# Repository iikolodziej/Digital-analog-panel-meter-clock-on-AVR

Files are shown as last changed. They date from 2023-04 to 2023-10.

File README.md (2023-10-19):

# Digital-analog-panel-meter-clock-on-AVR
Digital-analog panel meter clock created with AVR Atmega328 and voltage panel meter
Main photo

## Introduction
One of the assignments at the technical university was to design a simple alarm clock. I always wanted to have a more elaborate clock made by myself - so I went further and created a clock that is a combination of modernity and tradition.
<br /> 

## Technologies Used

### Languages


### Tools and others
  

### Microcontroller


## PURPOSE: 
making a clock based on analog and OLED displays with an alarm clock function

## PRINCIPLE OF OPERATION: 
In normal mode, the system alternately displays the time and date, temperature and atmospheric pressure on the OLED screen. After pressing the button, it allows you to set the current time and alarm clock. The current hour and minute are constantly displayed on analog displays

## PARAMETERS AND FUNCTIONS: 
displaying the current time and date as well as ambient temperature and atmospheric pressure. Possibility to set an alarm clock. Magnetic connection of the power cord. Possibility of easy programming via USB and ISP.

## WORKING CONDITIONS: 
home use conditions, splash protection

## POWER SUPPLY:
mains with battery time backup

## PRECISION:
○ timekeeping accuracy better than 1 s per day,<br /> 
○ temperature measurement accuracy with an accuracy of ± 0.5°C in the range of -10 to 85°C,<br /> 
○ accuracy of atmospheric pressure measurement ± 0.06 hPa in the range of 300 - 1100 hPa<br /> 

## DIMENSIONS AND WEIGHT:
approx. 25x15x15cm, up to 500g

## HOUSING: 
plastic, transparent

## Main components:
○ Microcontroller: Atmega328P-PU<br /> 
○ Real-time chip: DS1307<br /> 
○ Analog display: 2x panel voltmeter 0-5V DC<br /> 
○ Alphanumeric display: OLED 0.91"<br /> 
○ Temperature sensor: DS18B20<br /> 
○ Barometer: BMP180<br /> 

# ELECTRONIC SCHEMATIC
obraz

# PCB
obraz

# 3D DESIGN
obraz

# 3D PRINT & MECHANICS
obraz

# ASSEMBLY STAGES
obraz

# FINAL ASSEMBLY
obraz

# START-UP AND SYSTEM TESTS
obraz

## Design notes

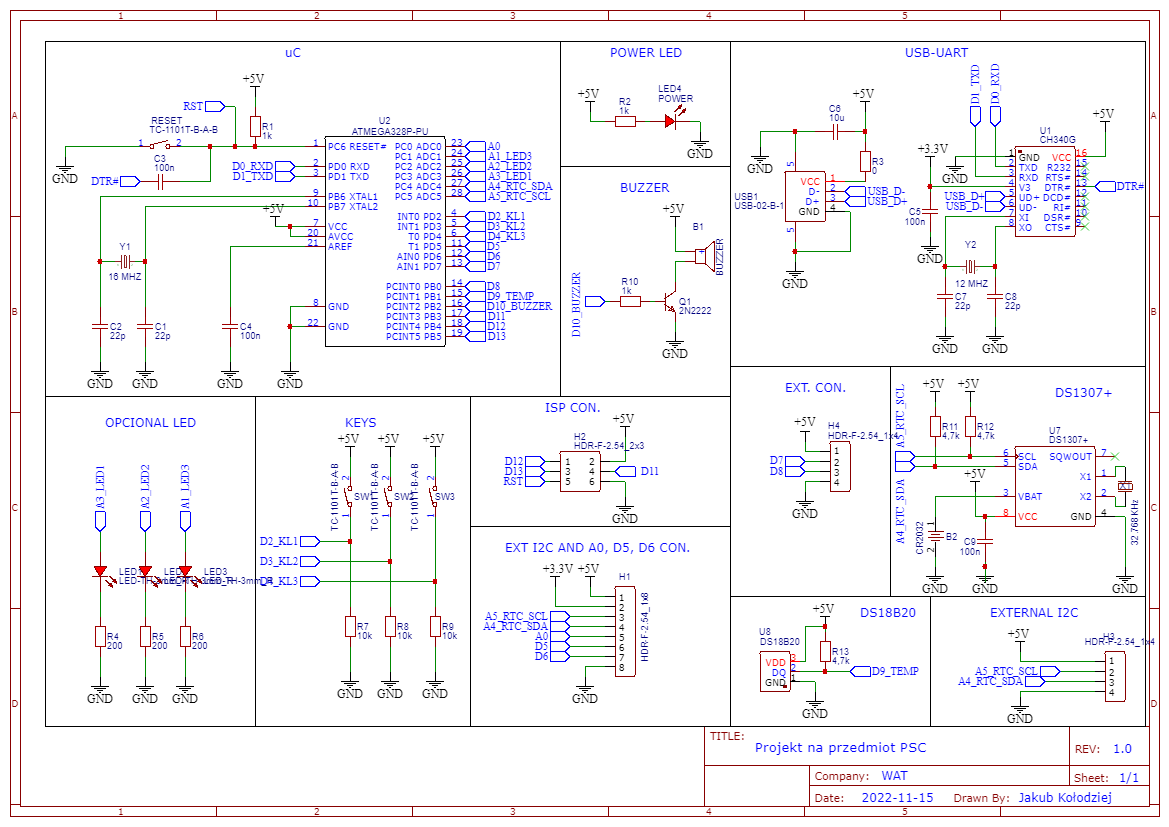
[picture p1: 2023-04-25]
images/Schematic_Budzik_JakubKolodziej_2023-01-18.png

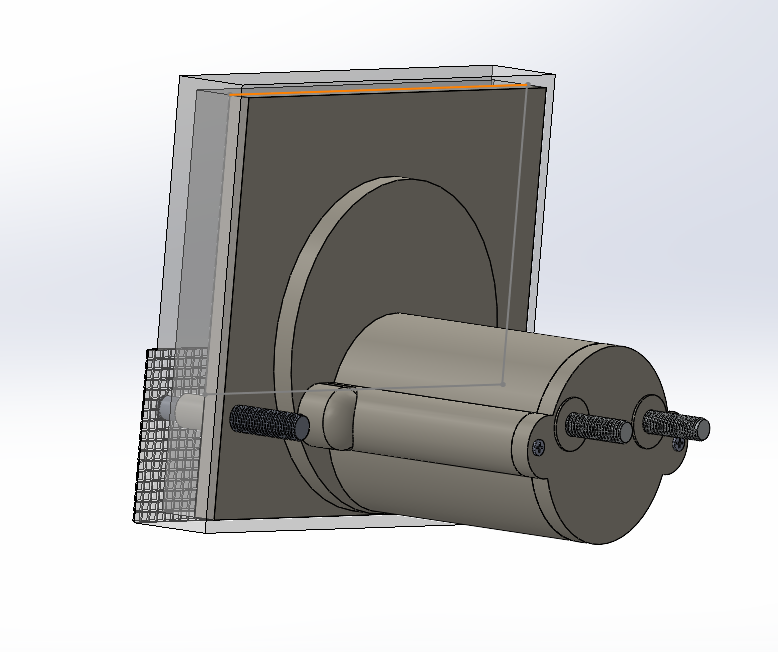
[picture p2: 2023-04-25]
images/panel meter2.png

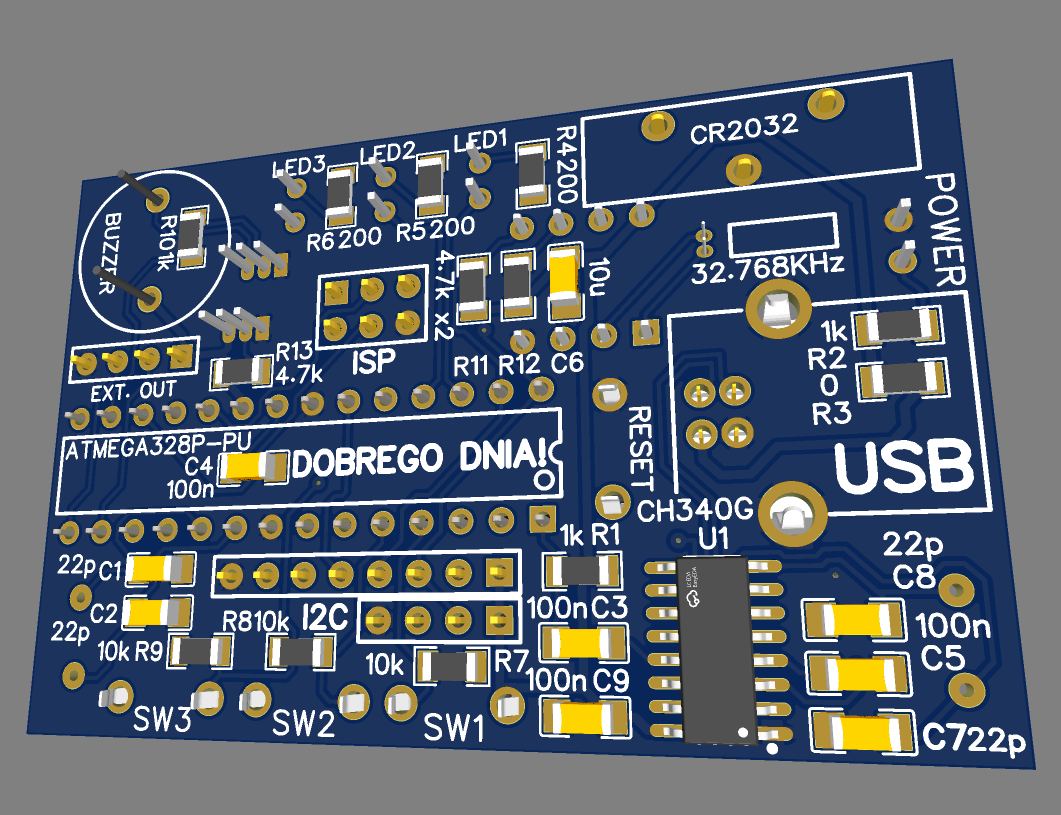
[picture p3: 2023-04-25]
images/pcb 3d bottom .png

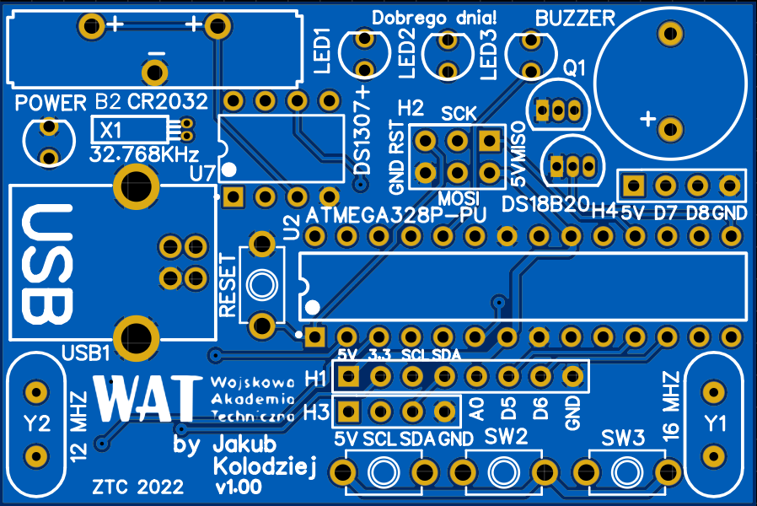
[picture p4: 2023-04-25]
images/pcb top psc.png

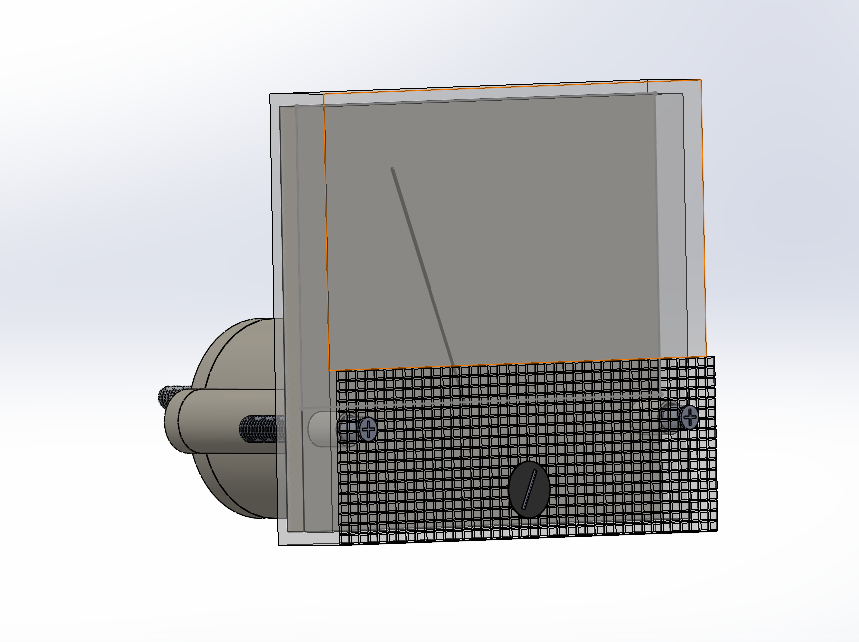
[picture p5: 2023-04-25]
images/panel meter.png

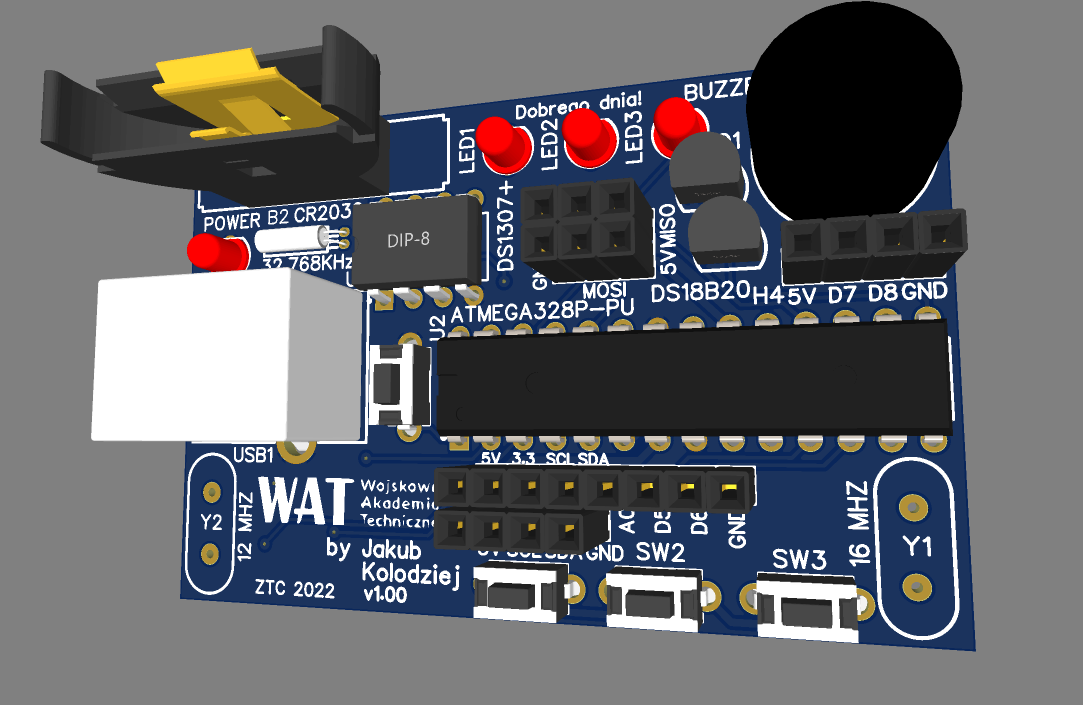
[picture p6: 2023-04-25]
images/pcb 3d top.png

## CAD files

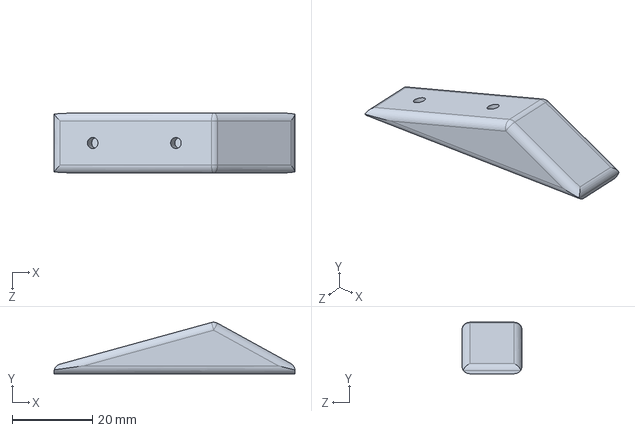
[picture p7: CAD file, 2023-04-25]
CAD elements/uchwyt podstawy do zegara analogowego.SLDPRT
60.0 x 12.9 x 15.0 mm

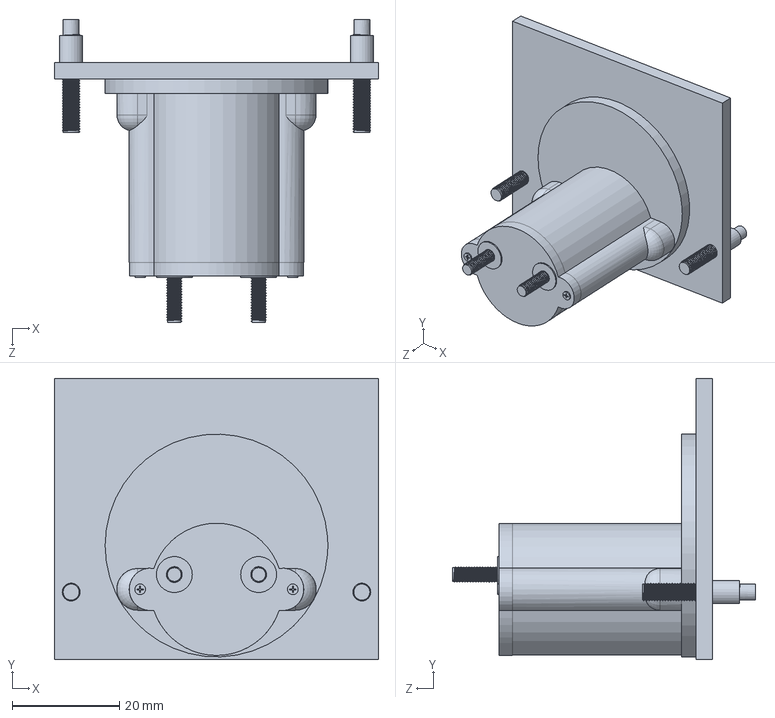
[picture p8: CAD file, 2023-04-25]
CAD elements/part001.SLDPRT
60.3 x 52.3 x 56.3 mm

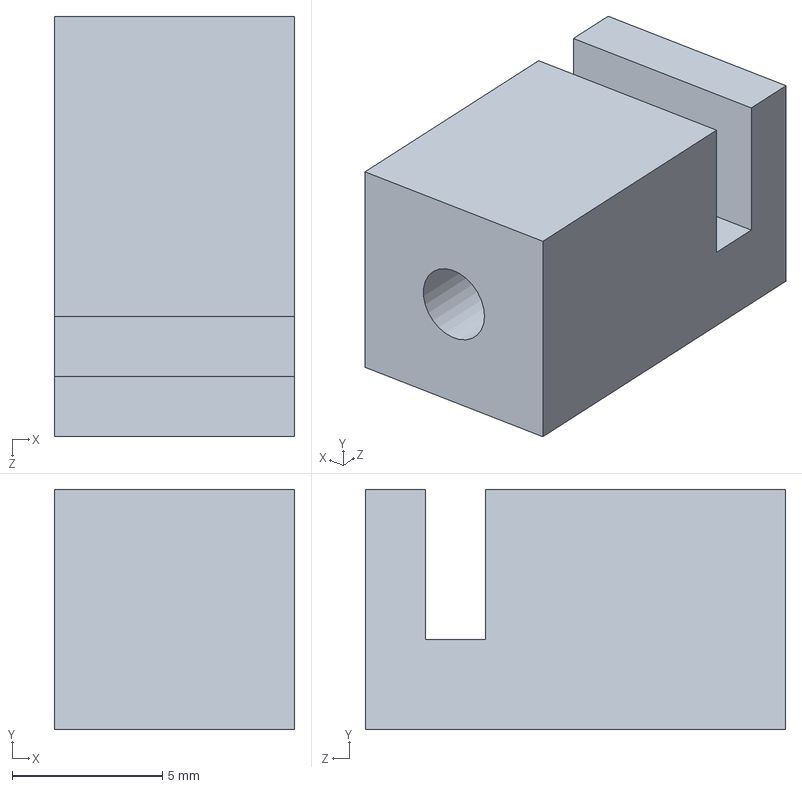
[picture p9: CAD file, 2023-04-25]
CAD elements/uchwyt 2 do zegara analogowego.SLDPRT
8.00 x 8.00 x 14.0 mm

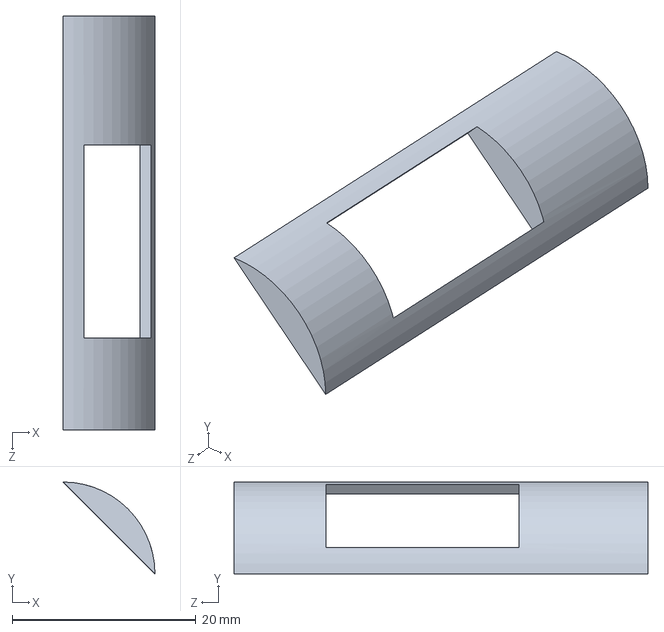
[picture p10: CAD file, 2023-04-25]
CAD elements/uchwyt 4 do zegara analogowego.SLDPRT
10.0 x 10.0 x 45.0 mm

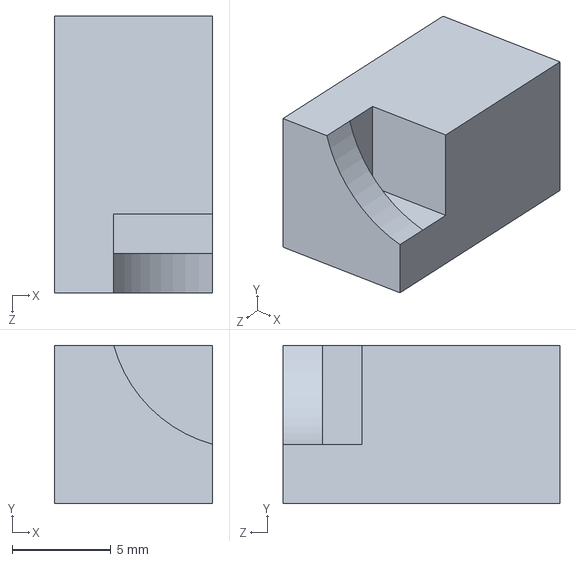
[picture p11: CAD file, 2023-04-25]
CAD elements/uchwyt 3 do zegara analogowego.SLDPRT
8.00 x 8.00 x 14.0 mm

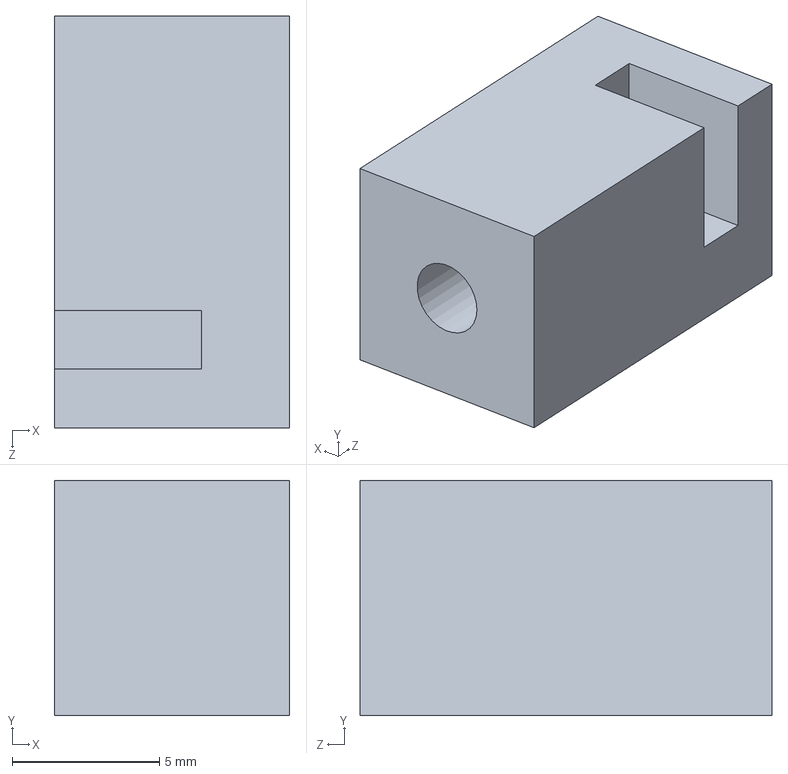
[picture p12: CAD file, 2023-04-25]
CAD elements/uchwyt 1 do zegara analogowego.SLDPRT
8.00 x 8.00 x 14.0 mm

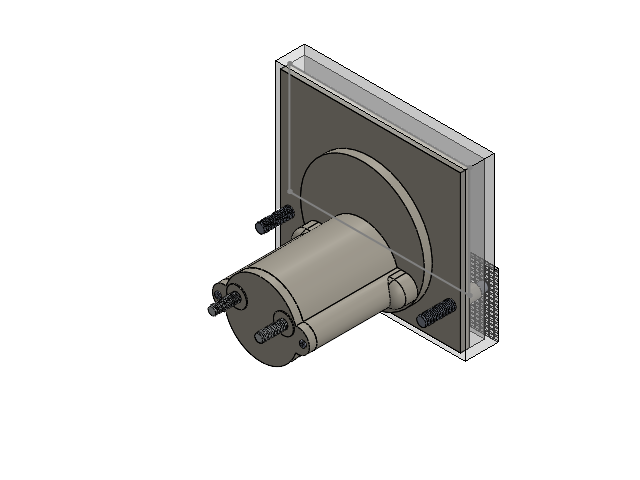
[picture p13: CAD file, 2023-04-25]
CAD elements/Assem3.SLDASM
Part3^Assem3
Part4^Assem3

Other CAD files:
CAD elements/uchwyt 1 do zegara analogowego.STL
CAD elements/uchwyt 2 do zegara analogowego.STL
CAD elements/uchwyt 3 do zegara analogowego.STL
CAD elements/uchwyt 4 do zegara analogowego.STL
CAD elements/uchwyt podstawy do zegara analogowego.STL

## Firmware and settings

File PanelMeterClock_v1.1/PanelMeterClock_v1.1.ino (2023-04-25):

/*



   Clock Display for PSC Lab in Military University of Technology


  @by Jakub Kołodziej



 */
 
#include <Wire.h>
#include <RTClib.h>
#include <Adafruit_SSD1306.h>
#include <OneWire.h>
#include <DallasTemperature.h>
#include <Adafruit_BMP085.h>
#include <EEPROM.h>

#define SCREEN_WIDTH 128 // OLED display width, in pixels
#define SCREEN_HEIGHT 32 // OLED display height, in pixels

#define OLED_RESET     -1 // Reset pin # (or -1 if sharing Arduino reset pin)
#define SCREEN_ADDRESS 0x3C ///< See datasheet for Address; 0x3D for 128x64, 0x3C for 128x32
Adafruit_SSD1306 display(SCREEN_WIDTH, SCREEN_HEIGHT, &Wire, OLED_RESET);

RTC_DS1307 rtc;

//define mbp180
Adafruit_BMP085 bmp;

/*************************DS18B20 temperature settings****************************/
// Data wire is plugged into pin 2 on the Arduino 
#define ONE_WIRE_BUS 9 
/********************************************************************/
// Setup a oneWire instance to communicate with any OneWire devices  
// (not just Maxim/Dallas temperature ICs) 
OneWire oneWire(ONE_WIRE_BUS); 
/********************************************************************/
// Pass our oneWire reference to Dallas Temperature. 
DallasTemperature sensors(&oneWire);
/********************************************************************/ 

// define pins usage
#define HOURPWM 5    //hour pwm out
#define MINPWM  6    //minutes pwm out

#define ADJ_SET 2    // Button SET MENU
#define ADJ_MINUS 3  // Button -
#define ADJ_PLUS  4  // Button +

#define ALARM_ON_OFF 8 //pin to set on/off of the alarm

// // buzzer pin
// #define BUZZER 10

// leds pins 
#define LED1 A3
#define LED2 A2
#define LED3 A1

//pin to set ground to the analog hour display
#define GROUND_HOUR 14

//pin to set ground to the alarm pin
#define GROUND_ALARM 7

//other variables
unsigned long previousMillis = 0;
const long interval = 2000;

uint8_t alarmHours = 0, alarmMinutes = 0;  // Holds the current alarm time

//variables for setting the rtc data
int hourupg;
int minupg;
int yearupg;
int monthupg;
int dayupg;
int menu = 0;

//char days of the week
char daysOfTheWeek[7][12] = {"Sun", "Mon", "Tue", "Wed", "Thu", "Fri", "Sat"};

DateTime theTime; 			// Current clock time

// PWM values for hours 0 to 12

byte hPwm[] = { 
	13, 33, 51, 70, 89, 108, 126, 145, 164, 183, 203, 222, 241 
};

// PWM values for Minuets 0 to 59 

byte mPwm[] = { 
	  4,   7,  11,  15,  20,  23,  28,  31,  35,  39,
	 42,  47,  51,  54,  58,  62,  66,  70,  74,  78,
	 82,  86,  90,  94,  97, 101, 105, 109, 113, 117,
	120, 124, 128, 132, 137, 141, 145, 149, 154, 158,
	161, 165, 169, 173, 177, 181, 185, 189, 193, 197,
	201, 205, 209, 213, 217, 221, 225, 229, 233, 237 
};



//notes for alarm song

#define NOTE_B0  31
#define NOTE_C1  33
#define NOTE_CS1 35
#define NOTE_D1  37
#define NOTE_DS1 39
#define NOTE_E1  41
#define NOTE_F1  44
#define NOTE_FS1 46
#define NOTE_G1  49
#define NOTE_GS1 52
#define NOTE_A1  55
#define NOTE_AS1 58
#define NOTE_B1  62
#define NOTE_C2  65
#define NOTE_CS2 69
#define NOTE_D2  73
#define NOTE_DS2 78
#define NOTE_E2  82
#define NOTE_F2  87
#define NOTE_FS2 93
#define NOTE_G2  98
#define NOTE_GS2 104
#define NOTE_A2  110
#define NOTE_AS2 117
#define NOTE_B2  123
#define NOTE_C3  131
#define NOTE_CS3 139
#define NOTE_D3  147
#define NOTE_DS3 156
#define NOTE_E3  165
#define NOTE_F3  175
#define NOTE_FS3 185
#define NOTE_G3  196
#define NOTE_GS3 208
#define NOTE_A3  220
#define NOTE_AS3 233
#define NOTE_B3  247
#define NOTE_C4  262
#define NOTE_CS4 277
#define NOTE_D4  294
#define NOTE_DS4 311
#define NOTE_E4  330
#define NOTE_F4  349
#define NOTE_FS4 370
#define NOTE_G4  392
#define NOTE_GS4 415
#define NOTE_A4  440
#define NOTE_AS4 466
#define NOTE_B4  494
#define NOTE_C5  523
#define NOTE_CS5 554
#define NOTE_D5  587
#define NOTE_DS5 622
#define NOTE_E5  659
#define NOTE_F5  698
#define NOTE_FS5 740
#define NOTE_G5  784
#define NOTE_GS5 831
#define NOTE_A5  880
#define NOTE_AS5 932
#define NOTE_B5  988
#define NOTE_C6  1047
#define NOTE_CS6 1109
#define NOTE_D6  1175
#define NOTE_DS6 1245
#define NOTE_E6  1319
#define NOTE_F6  1397
#define NOTE_FS6 1480
#define NOTE_G6  1568
#define NOTE_GS6 1661
#define NOTE_A6  1760
#define NOTE_AS6 1865
#define NOTE_B6  1976
#define NOTE_C7  2093
#define NOTE_CS7 2217
#define NOTE_D7  2349
#define NOTE_DS7 2489
#define NOTE_E7  2637
#define NOTE_F7  2794
#define NOTE_FS7 2960
#define NOTE_G7  3136
#define NOTE_GS7 3322
#define NOTE_A7  3520
#define NOTE_AS7 3729
#define NOTE_B7  3951
#define NOTE_C8  4186
#define NOTE_CS8 4435
#define NOTE_D8  4699
#define NOTE_DS8 4978
#define REST      0


// change this to make the song slower or faster
int tempo = 76;

// change this to whichever pin you want to use
int buzzer = 10;

// notes of the moledy followed by the duration.
// a 4 means a quarter note, 8 an eighteenth , 16 sixteenth, so on
// !!negative numbers are used to represent dotted notes,
// so -4 means a dotted quarter note, that is, a quarter plus an eighteenth!!
int melody[] = {

  // Wiegenlied (Brahms' Lullaby)
  // Score available at https://www.flutetunes.com/tunes.php?id=54

  NOTE_G4, 4, NOTE_G4, 4, //1
  NOTE_AS4, -4, NOTE_G4, 8, NOTE_G4, 4,
  NOTE_AS4, 4, REST, 4, NOTE_G4, 8, NOTE_AS4, 8,
  NOTE_DS5, 4, NOTE_D5, -4, NOTE_C5, 8,
  NOTE_C5, 4, NOTE_AS4, 4, NOTE_F4, 8, NOTE_G4, 8,
  NOTE_GS4, 4, NOTE_F4, 4, NOTE_F4, 8, NOTE_G4, 8,
  NOTE_GS4, 4, REST, 4, NOTE_F4, 8, NOTE_GS4, 8,
  NOTE_D5, 8, NOTE_C5, 8, NOTE_AS4, 4, NOTE_D5, 4,

  NOTE_DS5, 4, REST, 4, NOTE_DS4, 8, NOTE_DS4, 8, //8
  NOTE_DS5, 2, NOTE_C5, 8, NOTE_GS4, 8,
  NOTE_AS4, 2, NOTE_G4, 8, NOTE_DS4, 8,
  NOTE_GS4, 4, NOTE_AS4, 4, NOTE_C5, 4,
  NOTE_AS4, 2, NOTE_DS4, 8, NOTE_DS4, 8,
  NOTE_DS5, 2, NOTE_C5, 8, NOTE_GS4, 8,
  NOTE_AS4, 2, NOTE_G4, 8, NOTE_DS4, 8,
  NOTE_AS4, 4, NOTE_G4, 4, NOTE_DS4, 4,
  NOTE_DS4, 2

};

// sizeof gives the number of bytes, each int valsmaue is composed of two bytes (16 bits)
// there are two values per note (pitch and duration), so for each note there are four bytes
int notes = sizeof(melody) / sizeof(melody[0]) / 2;

// this calculates the duration of a whole note in ms
int wholenote = (60000 * 4) / tempo;

int divider = 0, noteDuration = 0;


void setup() {
	//Serial for debugging
	Serial.begin(9600);
		// start clock
	Wire.begin();
	rtc.begin();

  if (! rtc.begin()) {
    Serial.println("Couldn't find RTC");
    Serial.flush();
    while (1) delay(10);
  }

if (! rtc.isrunning()) {
    Serial.println("RTC is NOT running, let's set the time!");
    // When time needs to be set on a new device, or after a power loss, the
    // following line sets the RTC to the date & time this sketch was compiled
    rtc.adjust(DateTime(F(__DATE__), F(__TIME__)));
    // This line sets the RTC with an explicit date & time, for example to set
    // January 21, 2014 at 3am you would call:
    // rtc.adjust(DateTime(2014, 1, 21, 3, 0, 0));
  }

	pinMode(HOURPWM, OUTPUT);			// hour pwm pin
	pinMode(MINPWM, OUTPUT);			// minute pwm pin

	pinMode(ADJ_SET, INPUT);	
	pinMode(ADJ_MINUS, INPUT);		
  pinMode(ADJ_PLUS, INPUT);		
  pinMode(ALARM_ON_OFF, INPUT_PULLUP);	    
  
  pinMode(GROUND_HOUR, OUTPUT);
  pinMode(GROUND_ALARM, OUTPUT);

  pinMode(LED1, OUTPUT);
  pinMode(LED2, OUTPUT);
  pinMode(LED3, OUTPUT);



  pinMode(buzzer, OUTPUT);
    

//set the ground to the pin of the analog hour display
  digitalWrite(GROUND_HOUR, LOW);	

//set the ground to the pin of the alarm
  digitalWrite(GROUND_ALARM, LOW);	

  // SSD1306_SWITCHCAPVCC = generate display voltage from 3.3V internally
  if(!display.begin(SSD1306_SWITCHCAPVCC, SCREEN_ADDRESS)) {
    Serial.println(F("SSD1306 allocation failed"));
    for(;;); // Don't proceed, loop forever
  }

  // Show initial display buffer contents on the screen --
  // the library initializes this with an Adafruit splash screen.

  // Clear the buffer
  display.clearDisplay();
  display.setTextSize(2);
  display.setTextColor(WHITE);

 // Start up the library of temperature sensor
 sensors.begin(); 


//interrupt
attachInterrupt(digitalPinToInterrupt(2), read_adj_set, FALLING);

bmp.begin();


  //update alarm sets from eeprom

    alarmHours = EEPROM.read(1);
    alarmMinutes = EEPROM.read(16);



}
void loop() {




if(digitalRead(ADJ_MINUS)== HIGH && digitalRead(ADJ_PLUS)== HIGH)                                                                                                                                                                     
  {
    display.setCursor(0, 0);
    display.print("SET ALARM");
    display.display();      // Show initial text
    delay(1000);
    display.clearDisplay();

    DisplaySetHourAll();
    DisplaySetMinuteAll();

    display.setCursor(0, 0);
    display.print("ALARM");
    display.setCursor(0, 18);
    display.print(alarmHours);
    display.print(":");
    display.print(alarmMinutes);
    display.display();      // Show initial text
    display.clearDisplay();
    delay(1500);
  }


//set the time with buttons
 if(digitalRead(ADJ_SET)==HIGH)
  {
   menu=menu+1;
   delay(100);
  }
// in which subroutine should we go?
  if (menu==0)
    {
     DisplayDateTime(); // void DisplayDateTime
     Alarm(); // Alarm control
    }
  if (menu==1)
    {
    DisplaySetHour();
    }
  if (menu==2)
    {
    DisplaySetMinute();
    }
  if (menu==3)
    {
    DisplaySetYear();
    }
  if (menu==4)
    {
    DisplaySetMonth();
    }
  if (menu==5)
    {
    DisplaySetDay();
    }
  if (menu==6)
    {
    StoreAgg(); 
    delay(500);
    menu=0;
    }
    delay(100);

}

void DisplayDateTime ()
{
// We show the current date and time
  DateTime now = rtc.now();

unsigned long currentMillis = millis();

if (currentMillis - previousMillis >= interval) {
  previousMillis = currentMillis;

    digitalWrite(LED1, HIGH);
    digitalWrite(LED2, HIGH);

    Serial.print(now.year(), DEC);
    Serial.print('/');
    Serial.print(now.month(), DEC);
    Serial.print('/');
    Serial.print(now.day(), DEC);
    Serial.print(" (");
    Serial.print(daysOfTheWeek[now.dayOfTheWeek()]);
    Serial.print(") ");
    Serial.print(now.hour(), DEC);
    Serial.print(':');
    Serial.print(now.minute(), DEC);
    Serial.print(':');
    Serial.print(now.second(), DEC);
    Serial.println();

    //display things
    display.setCursor(0, 0);
    display.print(now.year());
    display.print('/');
    display.print(now.month());
    display.print('/');
    display.print(now.day());
    display.setCursor(0, 18);
    display.print(daysOfTheWeek[now.dayOfTheWeek()]);
    display.print(" ");
    display.print(now.hour());
    display.print(':');

    //if the minute is less than 10 display "0" before the single numer of minute
    if(now.minute() < 10){
      display.print("0");
      display.print(now.minute());
    }
    else{
    display.print(now.minute());
    }

    
    display.display();      // Show initial text
    display.clearDisplay();
    



  analogWrite(HOURPWM, hPwm[now.hour()%12]);
	analogWrite(MINPWM, mPwm[now.minute()]);  


  monthupg=now.month();
  yearupg=now.year();
}
else{

    digitalWrite(LED1, LOW);
    digitalWrite(LED2, LOW);

sensors.requestTemperatures();

Serial.println(sensors.getTempCByIndex(0));

    display.setCursor(0, 0);
    display.print(sensors.getTempCByIndex(0));
    display.print((char)247);
    display.print("C");
    display.setCursor(0, 18);
    display.print(bmp.readPressure()/100);
    display.print(" hPa");

    display.display();      // Show initial text
    display.clearDisplay();


}

    

}

void DisplaySetHour()
{
// time setting
    display.clearDisplay();
    display.setCursor(0, 0);
    display.print("Set hour");
    Serial.println("Set hour");
    
  DateTime now = rtc.now();
  if(digitalRead(ADJ_PLUS)==HIGH)
  {
    if(hourupg==23)
    {
      hourupg=0;
    }
    else
    {
      hourupg=hourupg+1;
    }
  }
   if(digitalRead(ADJ_MINUS)==HIGH)
  {
    if(hourupg==0)
    {
      hourupg=23;
    }
    else
    {
      hourupg=hourupg-1;
    }
  }
      display.setCursor(0, 18);
    display.print(hourupg);
    Serial.println(hourupg);
    display.display();
    delay(200);
    display.clearDisplay();
//  
}

void DisplaySetMinute()
{
// Setting the minutes
    display.clearDisplay();
    display.setCursor(0, 0);
    display.print("Set minute");
    Serial.println("Set minute");
    display.display();

  if(digitalRead(ADJ_PLUS)==HIGH)
  {
    if (minupg==59)
    {
      minupg=0;
    }
    else
    {
      minupg=minupg+1;
    }
  }
   if(digitalRead(ADJ_MINUS)==HIGH)
  {
    if (minupg==0)
    {
      minupg=59;
    }
    else
    {
      minupg=minupg-1;
    }
  }
    
    display.setCursor(0, 18);
    display.print(minupg);
    Serial.println(minupg);
    display.display();
    delay(200);
    display.clearDisplay();
}
  
void DisplaySetYear()
{
// setting the year
    display.clearDisplay();
    display.setCursor(0, 0);
    display.print("Set year");
    Serial.println("Set year");
    
  if(digitalRead(ADJ_PLUS)==HIGH)
  {    
    yearupg=yearupg+1;
  }
   if(digitalRead(ADJ_MINUS)==HIGH)
  {
    yearupg=yearupg-1;
  }
      display.setCursor(0, 18);
    display.print(yearupg);
    Serial.println(yearupg);
    display.display();
    delay(200);
    display.clearDisplay();
}

void DisplaySetMonth()
{
// Setting the month
    display.clearDisplay();
    display.setCursor(0, 0);
    display.print("Set month");
    Serial.println("Set month");
  if(digitalRead(ADJ_PLUS)==HIGH)
  {
    if (monthupg==12)
    {
      monthupg=1;
    }
    else
    {
      monthupg=monthupg+1;
    }
  }
   if(digitalRead(ADJ_MINUS)==HIGH)
  {
    if (monthupg==1)
    {
      monthupg=12;
    }
    else
    {
      monthupg=monthupg-1;
    }
  }
      display.setCursor(0, 18);
    display.print(monthupg);
    Serial.println(monthupg);
    display.display();
    delay(200);
    display.clearDisplay();  delay(200);
}

void DisplaySetDay()
{
// Setting the day
    display.clearDisplay();
    display.setCursor(0, 0);
    display.print("Set day");
    Serial.println("Set day");

  if(digitalRead(ADJ_PLUS)==HIGH)
  {
    if (dayupg==31)
    {
      dayupg=1;
    }
    else
    {
      dayupg=dayupg+1;
    }
  }
   if(digitalRead(ADJ_MINUS)==HIGH)
  {
    if (dayupg==1)
    {
      dayupg=31;
    }
    else
    {
      dayupg=dayupg-1;
    }
  }
    display.setCursor(0, 18);
    display.print(dayupg);
    Serial.println(dayupg);
    display.display();
    delay(200);
    display.clearDisplay();
}

void StoreAgg()
{
      display.clearDisplay();
    display.setCursor(0, 0);
    display.print("Saving...");
    Serial.println("Saving");
    display.setCursor(0, 18);
    display.print("That's all!");
    display.display();
    delay(200);
    display.clearDisplay();
  rtc.adjust(DateTime(yearupg,monthupg,dayupg,hourupg,minupg,0));
    delay(200);
}

void read_adj_set(){
  
}


////alarm////

void DisplaySetHourAll()// Setting the alarm minutes
{
  while(digitalRead(ADJ_SET)==LOW){



  if(digitalRead(ADJ_PLUS)==HIGH)
  {
    if(alarmHours==23)
    {
      alarmHours=0;
    }
    else
    {
      alarmHours=alarmHours+1;
    }
  }
   if(digitalRead(ADJ_MINUS)==HIGH)
  {
    if(alarmHours==0)
    {
      alarmHours=23;
    }
    else
    {
      alarmHours=alarmHours-1;
    }
  }
    display.setCursor(0, 0);
    display.print("Set HOUR:");
    display.setCursor(0, 18);
    display.print(alarmHours);

    display.display();      // Show initial text
    display.clearDisplay();
    delay(200);
 }
  EEPROM.write(1, alarmHours);
 delay(200);
}




void DisplaySetMinuteAll()// Setting the alarm minutes
 {
  while(digitalRead(ADJ_SET)==LOW){ 


  if(digitalRead(ADJ_PLUS)==HIGH)
  {
    if (alarmMinutes==59)
    {
      alarmMinutes=0;
    }
    else
    {
      alarmMinutes=alarmMinutes+1;
    }
  }
   if(digitalRead(ADJ_MINUS)==HIGH)
  {
    if (alarmMinutes==0)
    {
      alarmMinutes=59;
    }
    else
    {
      alarmMinutes=alarmMinutes-1;
    }
  }

    display.setCursor(0, 0);
    display.print("Set MIN:");
    display.setCursor(0, 18);
    display.print(alarmMinutes);

    display.display();      // Show initial text
    display.clearDisplay();
    delay(200);
 }
   EEPROM.write(16, alarmMinutes);
 delay(200);
}



void Alarm(){

  if (digitalRead(ALARM_ON_OFF)== HIGH)
    {
    // printAllOff();
     noTone (buzzer);
     digitalWrite(LED3,LOW);
     }
  if (digitalRead(ALARM_ON_OFF)== LOW)
    {

     //printAllOn();    
     //led that state the alarm is on
    digitalWrite(LED3,HIGH);

       DateTime now = rtc.now();
     if ( (now.hour() == alarmHours) && (now.minute() == alarmMinutes) ) 
        {
        DateTime now = rtc.now();
         
        //  tone(BUZZER,880); //play the note 
        //  delay (300);
        //  tone(BUZZER,698); //play the note 
//-----------------------------------------------------------------------
          // iterate over the notes of the melody.
  // Remember, the array is twice the number of notes (notes + durations)
  for (int thisNote = 0; thisNote < notes * 2; thisNote = thisNote + 2) {

    // calculates the duration of each note
    divider = melody[thisNote + 1];
    if (divider > 0) {
      // regular note, just proceed
      noteDuration = (wholenote) / divider;
    } else if (divider < 0) {
      // dotted notes are represented with negative durations!!
      noteDuration = (wholenote) / abs(divider);
      noteDuration *= 1.5; // increases the duration in half for dotted notes
    }

    // we only play the note for 90% of the duration, leaving 10% as a pause
    tone(buzzer, melody[thisNote], noteDuration * 0.9);

    // Wait for the specief duration before playing the next note.
    delay(noteDuration);

    // stop the waveform generation before the next note.
    noTone(buzzer);
  }

  //----------------------------------------------------
        }
    else{
         noTone (buzzer);
        }
    
    } 
    delay(200);
}
